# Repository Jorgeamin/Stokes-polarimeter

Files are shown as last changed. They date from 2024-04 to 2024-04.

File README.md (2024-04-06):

# Stokes-polarimeter
Supplement documents for article "Homemade open-source full-Stokes polarimeter based on division of amplitude"

* [python](python): This folder contains python scripts for user interface.\
    main application file **stokes_polarimeter.py**\
     -line 517:  ### Here your put the result of the calibration of the photodiodes ###\
     -line 526:  ### Here your put the result of the calibration to obtain the Stokes parameters ###
  
* [firmware](firmware): This folder contains MPLAB Harmony 3 firmware that should be installed in an ATSAML21E16B\
    file **main.c**\
	-line 97:  /// Here your put the result of the calibration of the photodiodes ///\
	-line 106: /// Here your put the result of the calibration to obtain the Stokes parameters ///
	
* [pcb](pcb): This folder contains the Autodesk Eagle electronic design files.
* [3d](3d): This folder contains the 3D Autodesk Inventor, STEP and STL files.
* [pdf](pdf): This folder contains the electronic diagrams and the 3D assembly in PDF format.

-this repository uses submodules

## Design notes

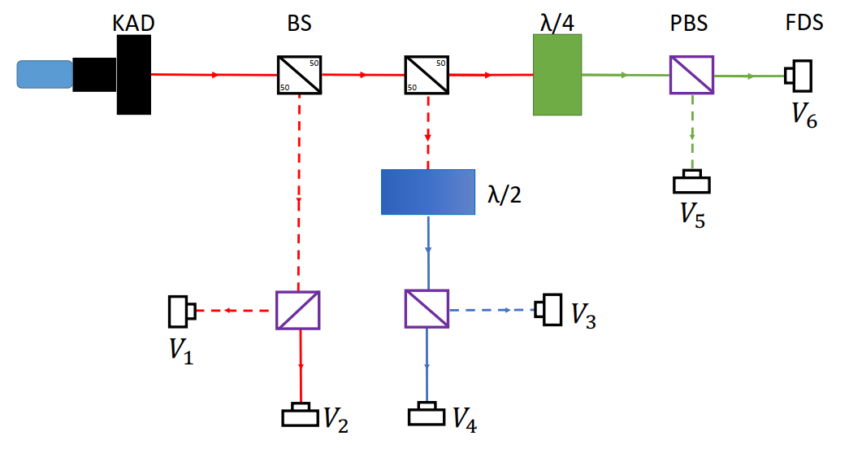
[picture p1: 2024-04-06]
python/figures/Polarization_analyzer_pds.png

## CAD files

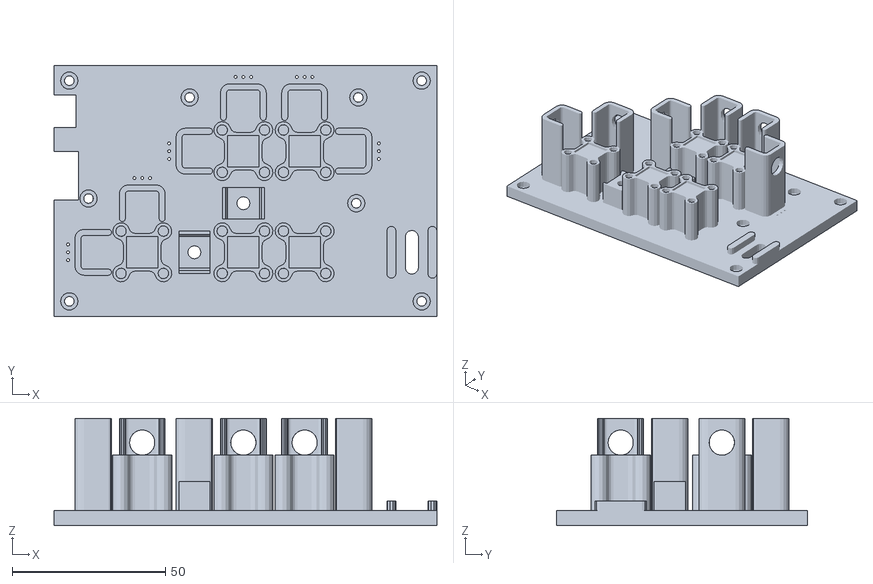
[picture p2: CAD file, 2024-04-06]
3d/3D_printer/base_main.stl
125.0 x 82.0 x 35.0

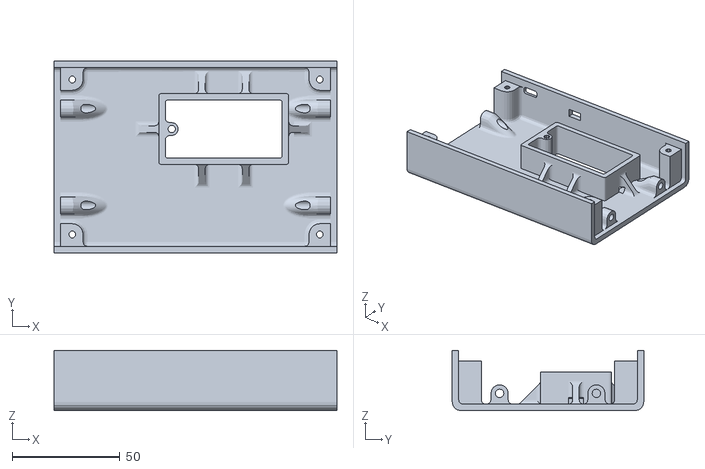
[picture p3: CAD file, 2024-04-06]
3d/3D_printer/case_box.stl
131.5 x 89.0 x 28.0

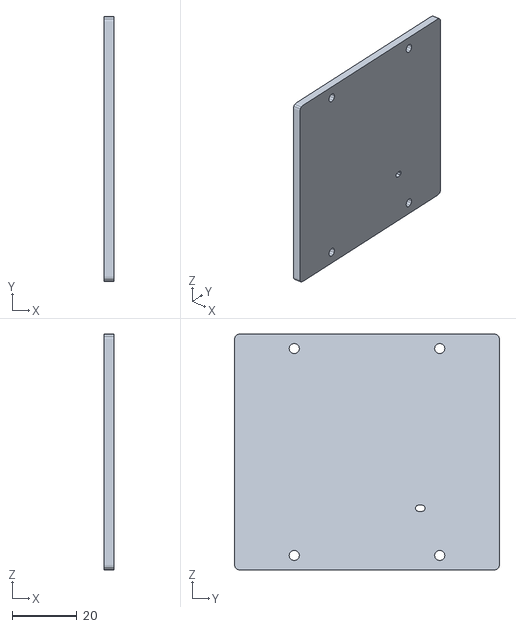
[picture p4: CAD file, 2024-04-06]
3d/3D_printer/case_rear.stl
3.00 x 82.0 x 73.0

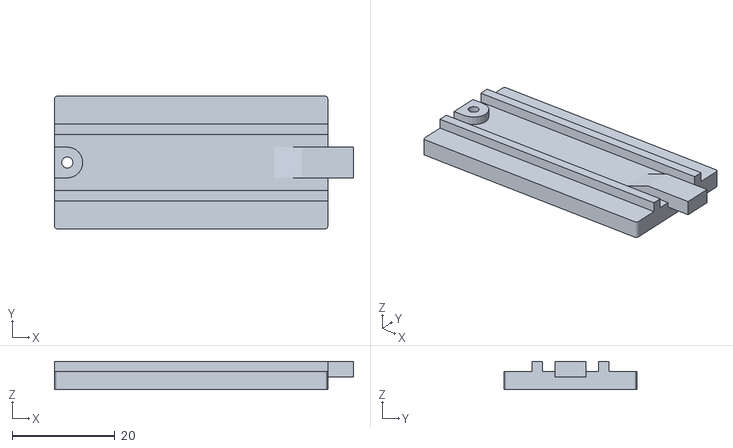
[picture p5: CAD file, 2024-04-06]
3d/3D_printer/case_battery_lid.stl
58.3 x 25.9 x 5.50

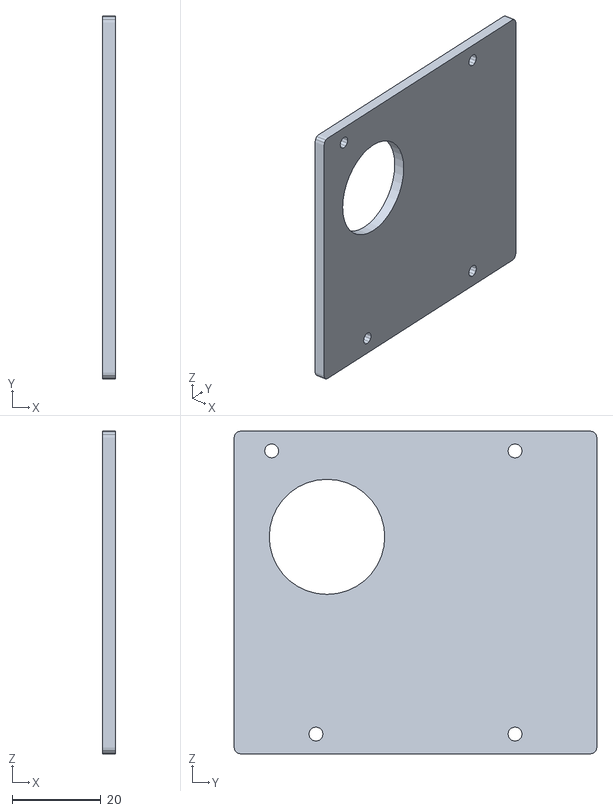
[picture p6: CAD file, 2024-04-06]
3d/3D_printer/case_front.stl
3.00 x 82.0 x 73.0

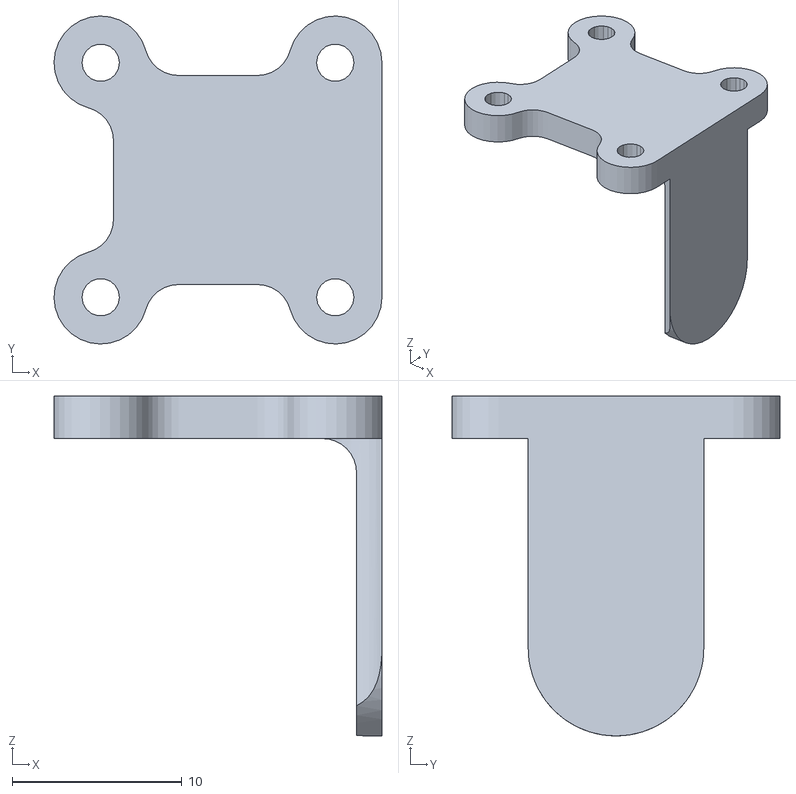
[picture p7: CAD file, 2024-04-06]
3d/3D_printer/lid_cube_wall.stl
19.3 x 19.3 x 20.0

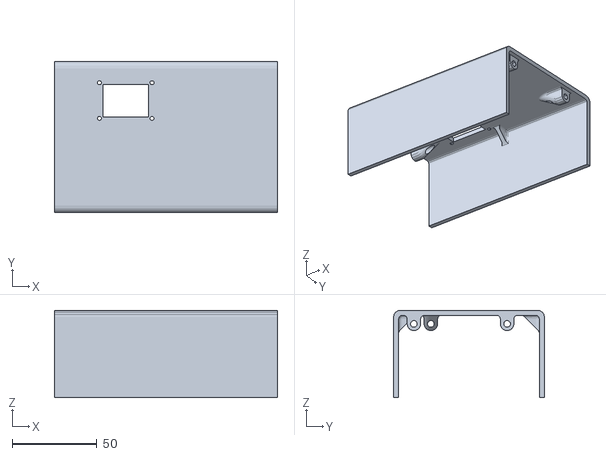
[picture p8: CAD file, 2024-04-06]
3d/3D_printer/case_lid.stl
131.5 x 89.0 x 51.5

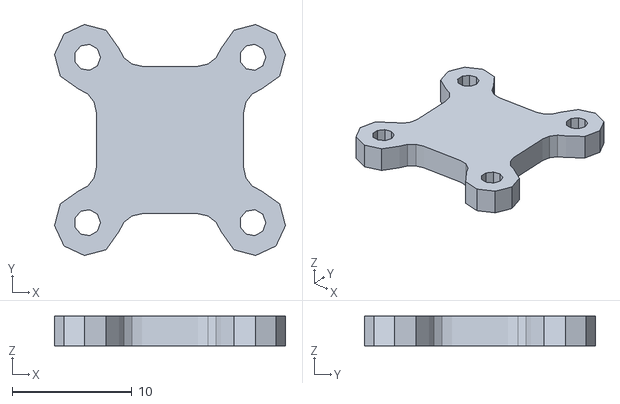
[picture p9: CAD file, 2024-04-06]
3d/3D_printer/lid_cube_x4.stl
19.3 x 19.3 x 2.50

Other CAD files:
3d/Inventor/components/DF13-4S-1.25C.ipt
3d/Inventor/components/Keystone_3348.ipt
3d/Inventor/components/TR Fastenings Ltd-M2X10mm.ipt
3d/Inventor/components/TR Fastenings Ltd-M2X16mm.ipt
3d/Inventor/components/TR Fastenings Ltd-M2_nut.ipt
3d/Inventor/components/TR Fastenings Ltd-M2_termal.ipt
3d/Inventor/components/TR Fastenings Ltd-M3X25mm.ipt
3d/Inventor/components/TR Fastenings Ltd-M3X8mm.ipt
3d/Inventor/components/TR Fastenings Ltd-M3_nut.ipt
3d/Inventor/components/TR Fastenings Ltd-M3_termal.ipt
3d/Inventor/components/TR Fastenings Ltd-M4X10mm.ipt
3d/Inventor/components/TR Fastenings Ltd-M4X18mm.ipt
3d/Inventor/components/acrylic.ipt
3d/Inventor/components/allen_2mm.ipt
3d/Inventor/components/base_cube.ipt
3d/Inventor/components/base_fotodiode.ipt
3d/Inventor/components/base_main.ipt
3d/Inventor/components/base_thor.ipt
3d/Inventor/components/box/battery_lid.ipt
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

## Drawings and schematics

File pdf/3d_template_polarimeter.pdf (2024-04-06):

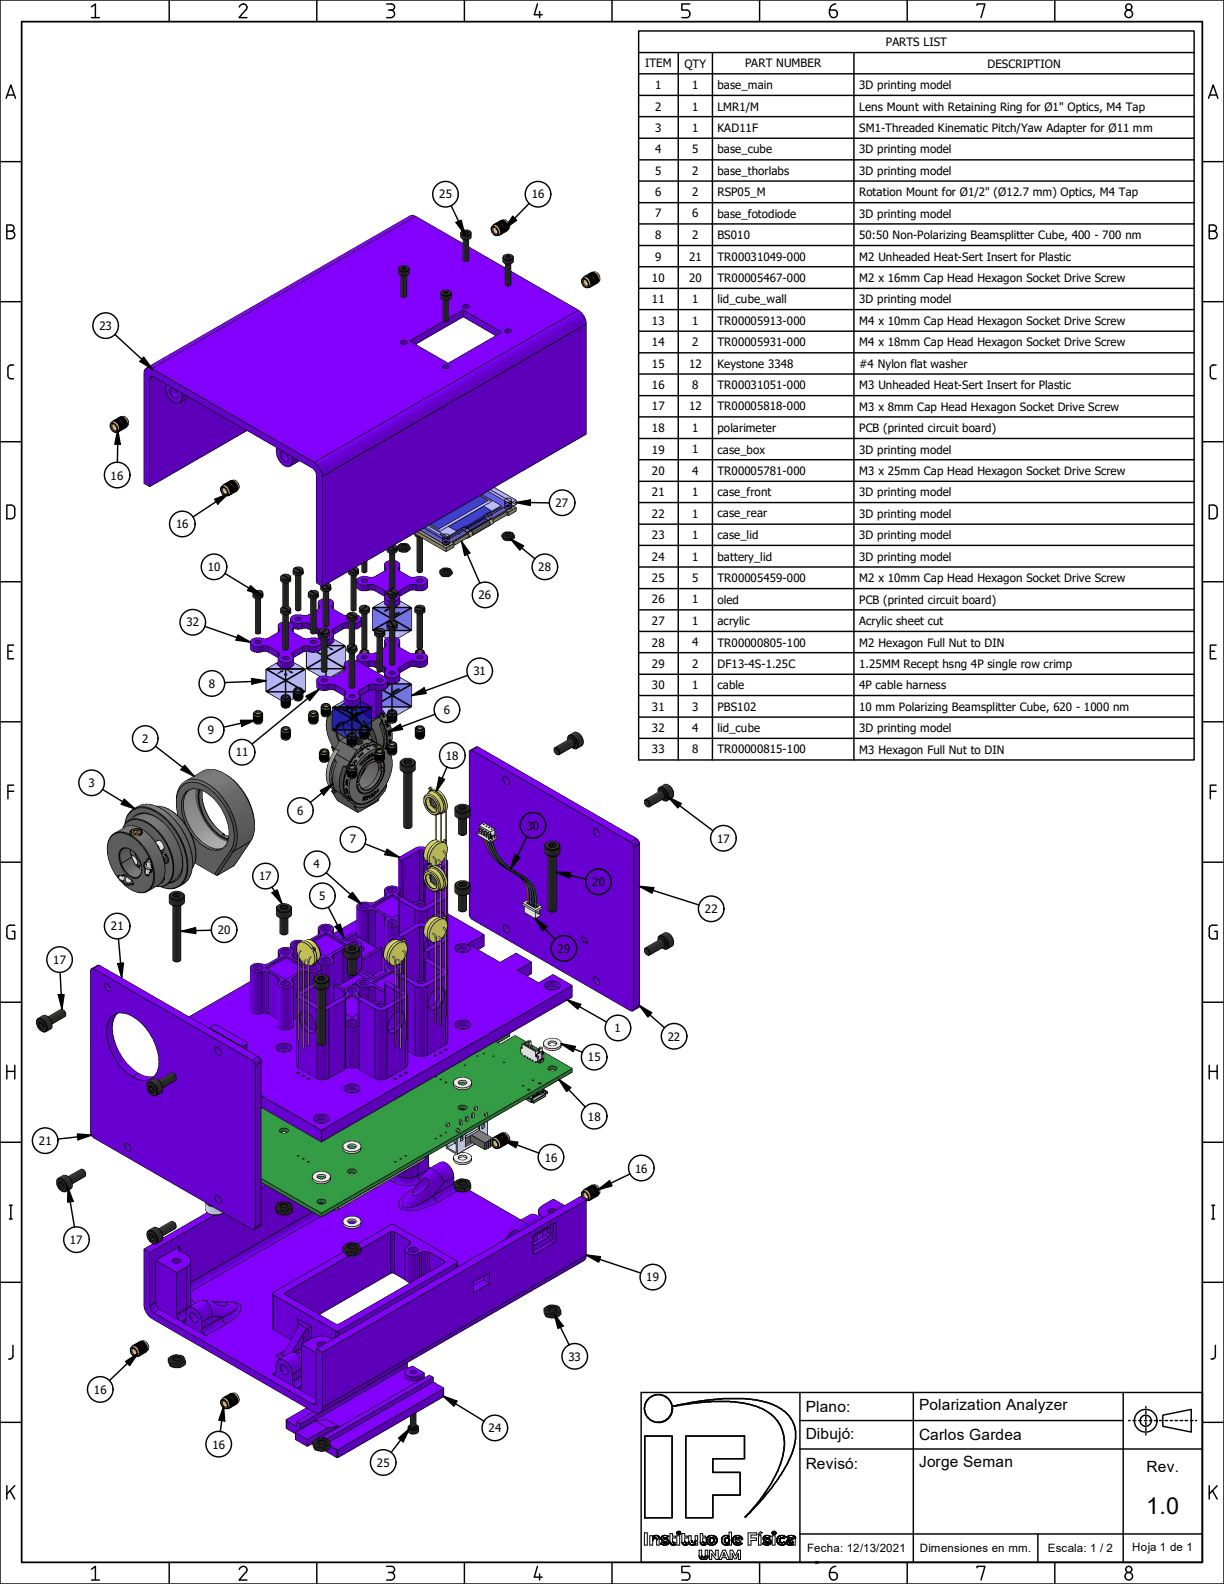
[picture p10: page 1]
PARTS LIST

ITEM | QTY | PART NUMBER | DESCRIPTION

1 | 1 | base_main | 3D printing model

2 | 1 | LMR1/M | Lens Mount with Retaining Ring for Ø1" Optics, M4 Tap

3 | 1 | KAD11F | SM1-Threaded Kinematic Pitch/Yaw Adapter for Ø11 mm

4 | 5 | base_cube | 3D printing model

5 | 2 | base_thorlabs | 3D printing model

6 | 2 | RSP05_M | Rotation Mount for Ø1/2" (Ø12.7 mm) Optics, M4 Tap

7 | 6 | base_fotodiode | 3D printing model

8 | 2 | BS010 | 50:50 Non-Polarizing Beamsplitter Cube, 400 - 700 nm

9 | 21 | TR00031049-000 | M2 Unheaded Heat-Sert Insert for Plastic

10 | 20 | TR00005467-000 | M2 x 16mm Cap Head Hexagon Socket Drive Screw

11 | 1 | lid_cube_wall | 3D printing model

13 | 1 | TR00005913-000 | M4 x 10mm Cap Head Hexagon Socket Drive Screw

14 | 2 | TR00005931-000 | M4 x 18mm Cap Head Hexagon Socket Drive Screw

15 | 12 | Keystone 3348 | #4 Nylon flat washer

16 | 8 | TR00031051-000 | M3 Unheaded Heat-Sert Insert for Plastic

17 | 12 | TR00005818-000 | M3 x 8mm Cap Head Hexagon Socket Drive Screw

18 | 1 | polarimeter | PCB (printed circuit board)

19 | 1 | case_box | 3D printing model

20 | 4 | TR00005781-000 | M3 x 25mm Cap Head Hexagon Socket Drive Screw

21 | 1 | case_front | 3D printing model
22 | 1 | case_rear | 3D printing model

23 | 1 | case_lid | 3D printing model

24 | 1 | battery_lid | 3D printing model

25 | 5 | TR00005459-000 | M2 x 10mm Cap Head Hexagon Socket Drive Screw

26 | 1 | oled | PCB (printed circuit board)

27 | 1 | acrylic | Acrylic sheet cut

28 | 4 | TR00000805-100 | M2 Hexagon Full Nut to DIN

29 | 2 | DF13-4S-1.25C | 1.25MM Recept hsng 4P single row crimp

30 | 1 | cable | 4P cable harness

31 | 3 | PBS102 | 10 mm Polarizing Beamsplitter Cube, 620 - 1000 nm

32 | 4 | lid_cube | 3D printing model

33 | 8 | TR00000815-100 | M3 Hexagon Full Nut to DIN

Plano: | Polarization Analyzer
Dibujó: | Carlos Gardea
Revisó: | Jorge Seman | Rev. 1.0

Fecha: 12/13/2021 | Dimensiones en mm. | Escala: 1 / 2 | Hoja 1 de 1

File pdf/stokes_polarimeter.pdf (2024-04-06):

## ATSAML21

A

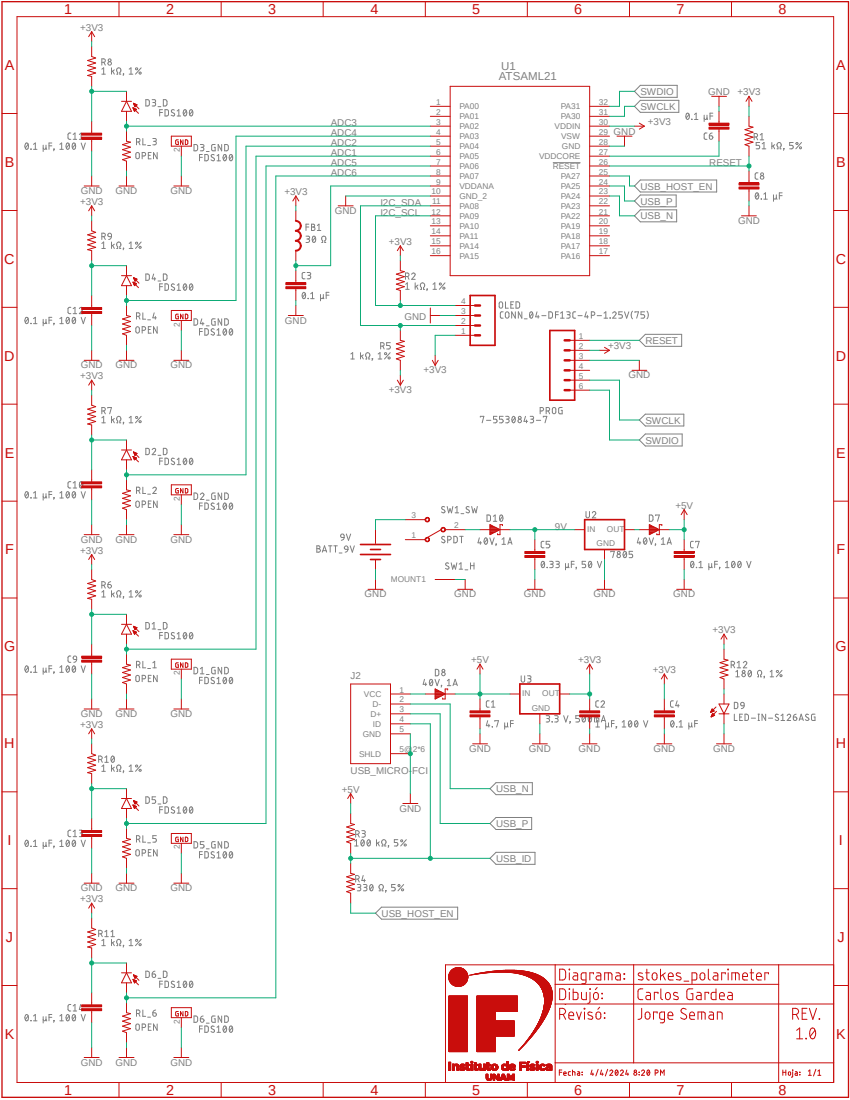
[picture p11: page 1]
USB_MICRO-FCI; GND; GND GND; VCC; 4 GND; 5 SHLD; OUT; VDDANA 9; GND_2 10; 25 RESET; 26 VDDCORE; 27 GND; 28 VSW; 29 VDDIN; 2 MOUNT1; SWDIO; SWCLK; RESET; USB_P; USB_N; USB_ID; USB_HOST_EN; ADC3 ADC4 ADC2 ADC1 ADC5 ADC6; I2C_SDA I2C_SCL

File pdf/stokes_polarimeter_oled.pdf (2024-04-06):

GND | GND

+3V3

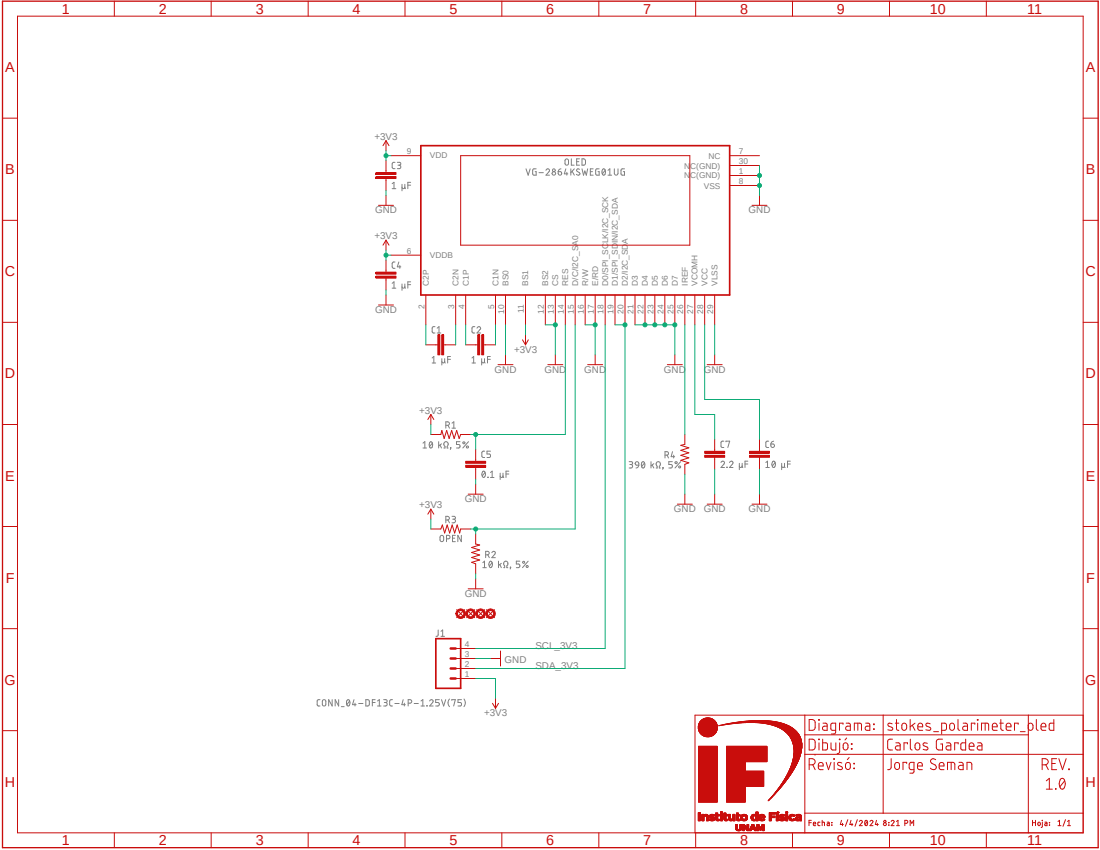
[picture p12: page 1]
GND; GND GND; NC(GND); 30 VLSS 29 VCC 28 VCOMH 27 IREF 26 D⁷ 25 D⁶ 24 D⁵ 23 D⁴ 22 D³ 21 D²/I2C_SDA 20 D¹/SPI_SDIN/I2C_SDA 19 D⁰/SPI_SCLK/I2C_SCK 18 E/RD 17 R/W 16 D/C/I2C_SA⁰ 15 RES 14 CS 13 BS² 12 BS¹ 11 BS⁰ 10 VDD 9; VSS; 7 VDDB 6; C¹N; 4 SCL_3V3; SDA_3V3

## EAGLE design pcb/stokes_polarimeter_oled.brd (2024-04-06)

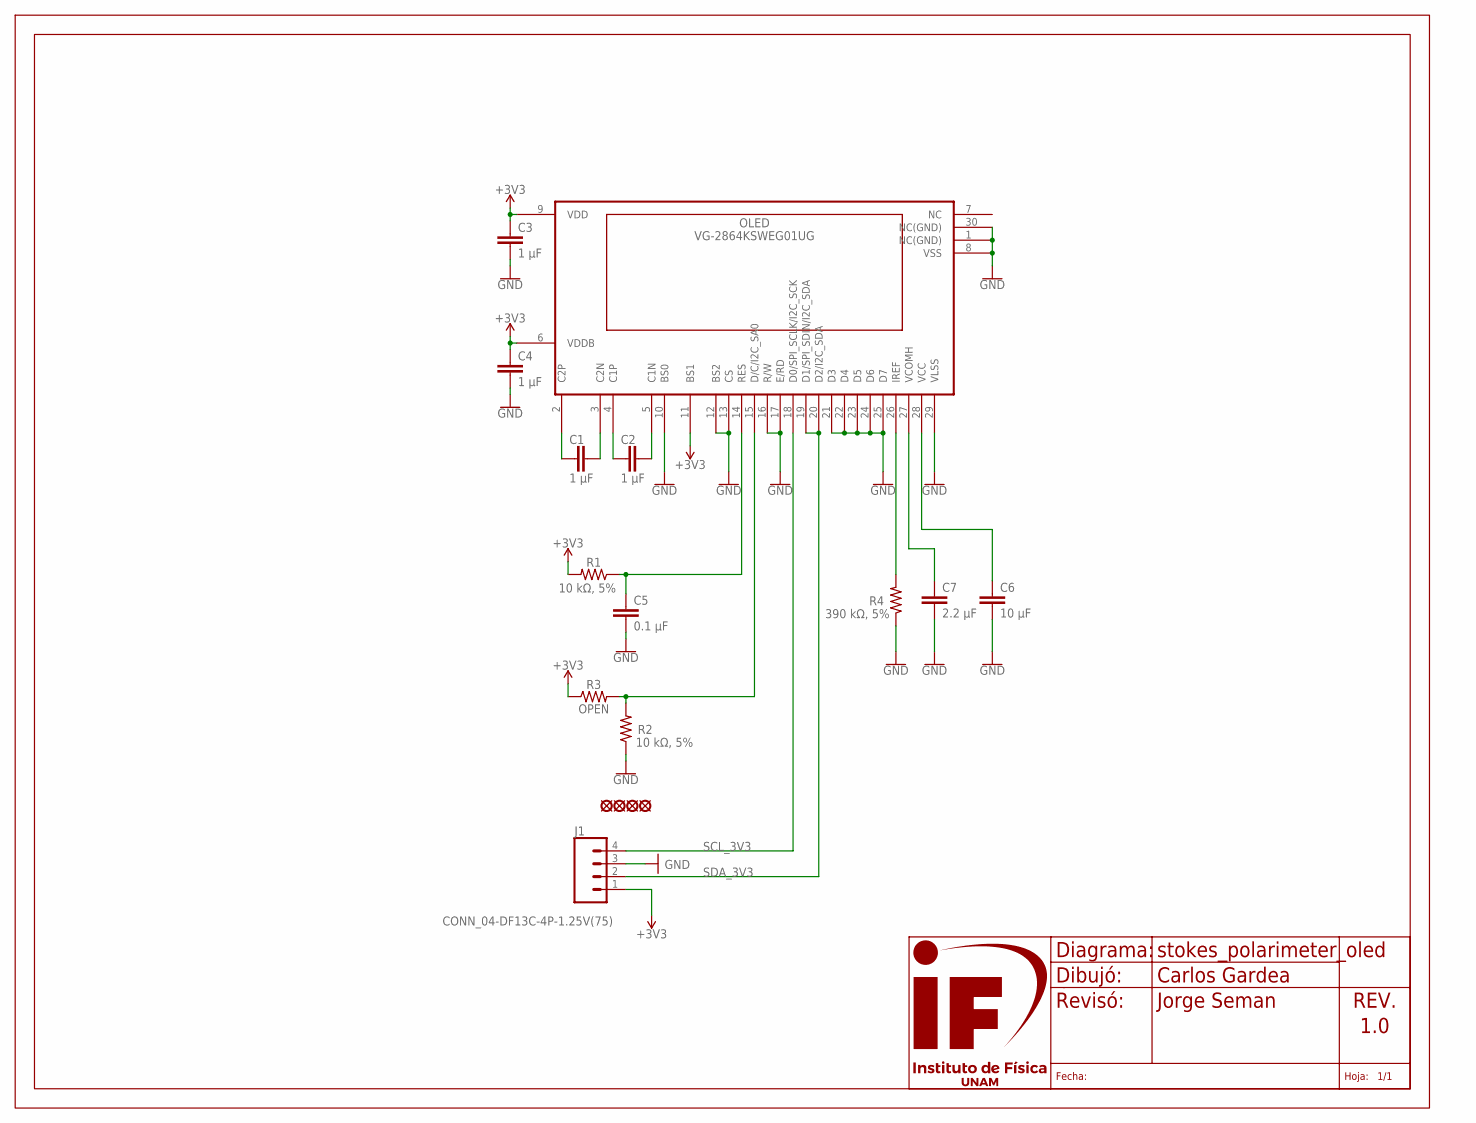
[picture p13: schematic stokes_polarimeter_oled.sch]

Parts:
C1, C2, C3, C4: 1 µF; C1206
C5: 0.1 µF; C1206
C6: 10 µF; C1206
C7: 2.2 µF; C1206
H5, H6, H7, H8: HOLE-M2.5; HOLE_2.5
J1: CONN_04-DF13C-4P-1.25V(75); DF13C4P125V
OLED: VG-2864KSWEG01UG; UG-2864HSWEG01
R1, R2: 10 kΩ, 5%; R1206
R3: OPEN; R1206_OPEN
R4: 390 kΩ, 5%; R1206
U$1: IFUNAM_FRAME_LETTER_HNONE; NONE

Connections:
+3V3: C3.1, C4.1, J1.1, OLED.6 (VDDB), OLED.9 (VDD), OLED.11 (BS1), R1.2, R3.1
GND: C3.2, C4.2, C5.2, C6.2, C7.2, J1.3, OLED.1 (NC(GND)), OLED.8 (VSS), OLED.10 (BS0), OLED.12 (BS2), OLED.13 (CS), OLED.16 (R/W), OLED.17 (E/RD), OLED.21 (D3), OLED.22 (D4), OLED.23 (D5), OLED.24 (D6), OLED.25 (D7), OLED.29 (VLSS), OLED.30 (NC(GND)), R2.1, R4.1
unnamed: C2.1, OLED.4 (C1P)
unnamed: C1.2, OLED.3 (C2N)
unnamed: C1.1, OLED.2 (C2P)
unnamed: C2.2, OLED.5 (C1N)
unnamed: C5.1, OLED.14 (RES), R1.1
unnamed: OLED.15 (D/C/I2C_SA0), R2.2, R3.2
unnamed: OLED.26 (IREF), R4.2
unnamed: C7.1, OLED.27 (VCOMH)
unnamed: C6.1, OLED.28 (VCC)
SCL_3V3: J1.4, OLED.18 (D0/SPI_SCLK/I2C_SCK)
SDA_3V3: J1.2, OLED.19 (D1/SPI_SDIN/I2C_SDA), OLED.20 (D2/I2C_SDA)

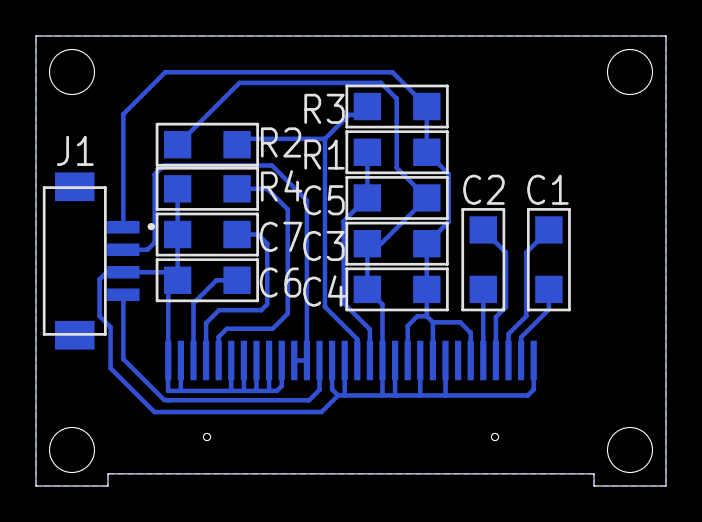
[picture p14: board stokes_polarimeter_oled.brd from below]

Board: 2 copper layers, 35.0 x 25.0 mm, 18 parts (12 on the bottom side), 13 nets.

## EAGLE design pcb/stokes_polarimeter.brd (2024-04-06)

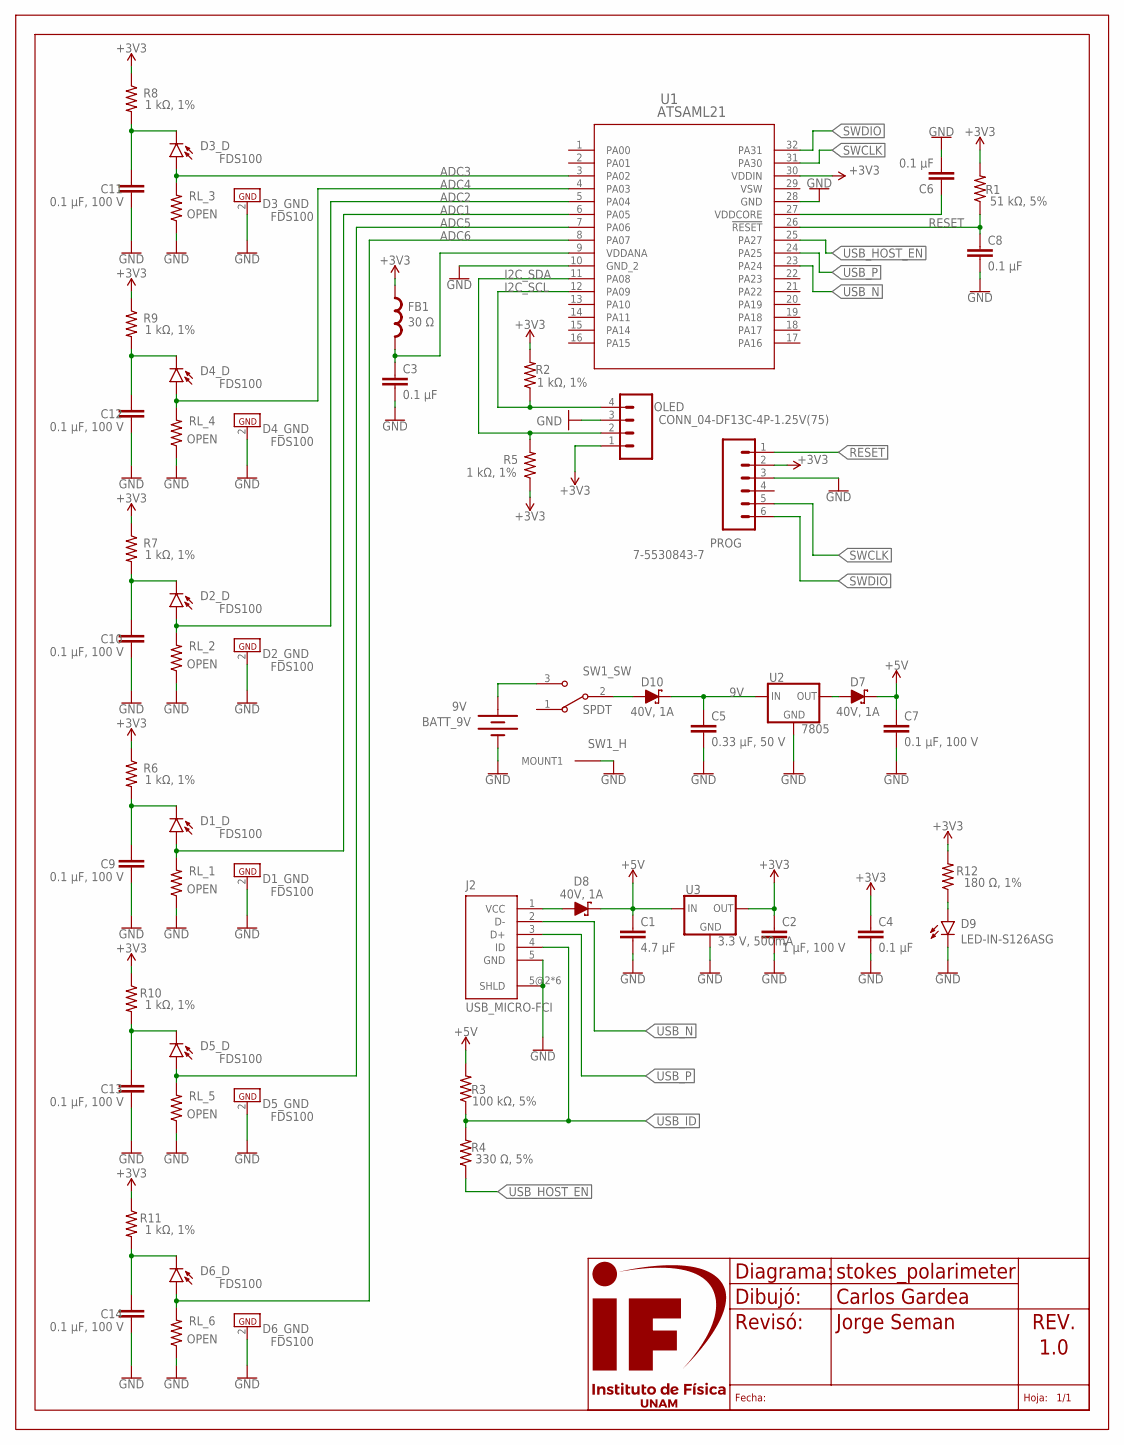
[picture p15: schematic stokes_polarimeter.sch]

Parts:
BATT_9V: 9V; 5331
C1: 4.7 µF; C1206
C2: 1 µF, 100 V; C1206
C3, C4, C6, C8: 0.1 µF; C1206
C5: 0.33 µF, 50 V; C1206
C7, C9, C10, C11, C12, C13, C14: 0.1 µF, 100 V; C1206
D1, D2, D3, D4, D5, D6: FDS100; FDS100_VERT
D7, D8, D10: 40V, 1A; DO-214AC
D9: LED-IN-S126ASG; IN-S126AS
FB1: 30 Ω; L1206
J2: USB_MICRO-FCI; 10103594-0001LF_FCI
OLED: CONN_04-DF13C-4P-1.25V(75); DF13C4P125V
PROG: 7-5530843-7
R1: 51 kΩ, 5%; R1206
R2, R5, R6, R7, R8, R9, R10, R11: 1 kΩ, 1%; R1206
R3: 100 kΩ, 5%; R1206
R4: 330 Ω, 5%; R1206
R12: 180 Ω, 1%; R1206
RL_1, RL_2, RL_3, RL_4, RL_5, RL_6: OPEN; R1206_OPEN
SW1: SPDT; SK12F17G7
U1: ATSAML21; TQFP32
U2: 7805; DPAK
U3: 3.3 V, 500mA; SOT223
U$54: IFUNAM_FRAME_LETTER_VNONE; NONE

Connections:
9V: C5.1, D10.K (C), U2.1 (IN)
+3V3: C2.1, C4.1, FB1.1, OLED.1, PROG.2, R1.2, R2.2, R5.1, R6.1, R7.1, R8.1, R9.1, R10.1, R11.1, R12.2, U1.30 (VDDIN), U3.3 (OUT)
+5V: C1.1, C7.1, D7.K (C), D8.K (C), R3.2, U3.1 (IN)
ADC1: D1.1 (A), RL_1.2, U1.6 (PA05)
ADC2: D2.1 (A), RL_2.2, U1.5 (PA04)
ADC3: D3.1 (A), RL_3.2, U1.3 (PA02)
ADC4: D4.1 (A), RL_4.2, U1.4 (PA03)
ADC5: D5.1 (A), RL_5.2, U1.7 (PA06)
ADC6: D6.1 (A), RL_6.2, U1.8 (PA07)
GND: BATT_9V.-, C1.2, C2.2, C3.2, C4.2, C5.2, C6.2, C7.2, C8.2, C9.2, C10.2, C11.2, C12.2, C13.2, C14.2, D1.2 (P$GND), D2.2 (P$GND), D3.2 (P$GND), D4.2 (P$GND), D5.2 (P$GND), D6.2 (P$GND), D9.K (C), J2.5 (GND), J2.5@2 (SHLD), J2.5@3 (SHLD), J2.5@4 (SHLD), J2.5@5 (SHLD), J2.5@6 (SHLD), J2.5@7 (SHLD), OLED.3, PROG.3, RL_1.1, RL_2.1, RL_3.1, RL_4.1, RL_5.1, RL_6.1, SW1.MH1 (MOUNT1), SW1.MH2 (MOUNT1), SW1.MH3 (MOUNT1), SW1.MH4 (MOUNT1), U1.10 (GND_2), U1.28 (GND), U2.4 (GND), U3.2 (GND), U3.4 (GND)
I2C_SCL: OLED.4, R2.1, U1.12 (PA09)
I2C_SDA: OLED.2, R5.2, U1.11 (PA08)
unnamed: C10.1, D2.3 (C), R7.2
unnamed: D10.A, SW1.2 (COMMON)
unnamed: C9.1, D1.3 (C), R6.2
unnamed: D9.A, R12.1
unnamed: C11.1, D3.3 (C), R8.2
unnamed: BATT_9V.+, SW1.3 (NO)
unnamed: C12.1, D4.3 (C), R9.2
unnamed: C13.1, D5.3 (C), R10.2
unnamed: C14.1, D6.3 (C), R11.2
unnamed: D7.A, U2.3 (OUT)
unnamed: D8.A, J2.1 (VCC)
RESET: C8.1, PROG.1, R1.1, U1.26 (!RESET)
SWCLK: PROG.5, U1.31 (PA30)
SWDIO: PROG.6, U1.32 (PA31)
USB_HOST_EN: R4.1, U1.25 (PA27)
USB_ID: J2.4 (ID), R3.1, R4.2
USB_N: J2.2 (D-), U1.23 (PA24)
USB_P: J2.3 (D+), U1.24 (PA25)
VDDANA: C3.1, FB1.2, U1.9 (VDDANA)
VDDCORE: C6.1, U1.27 (VDDCORE)

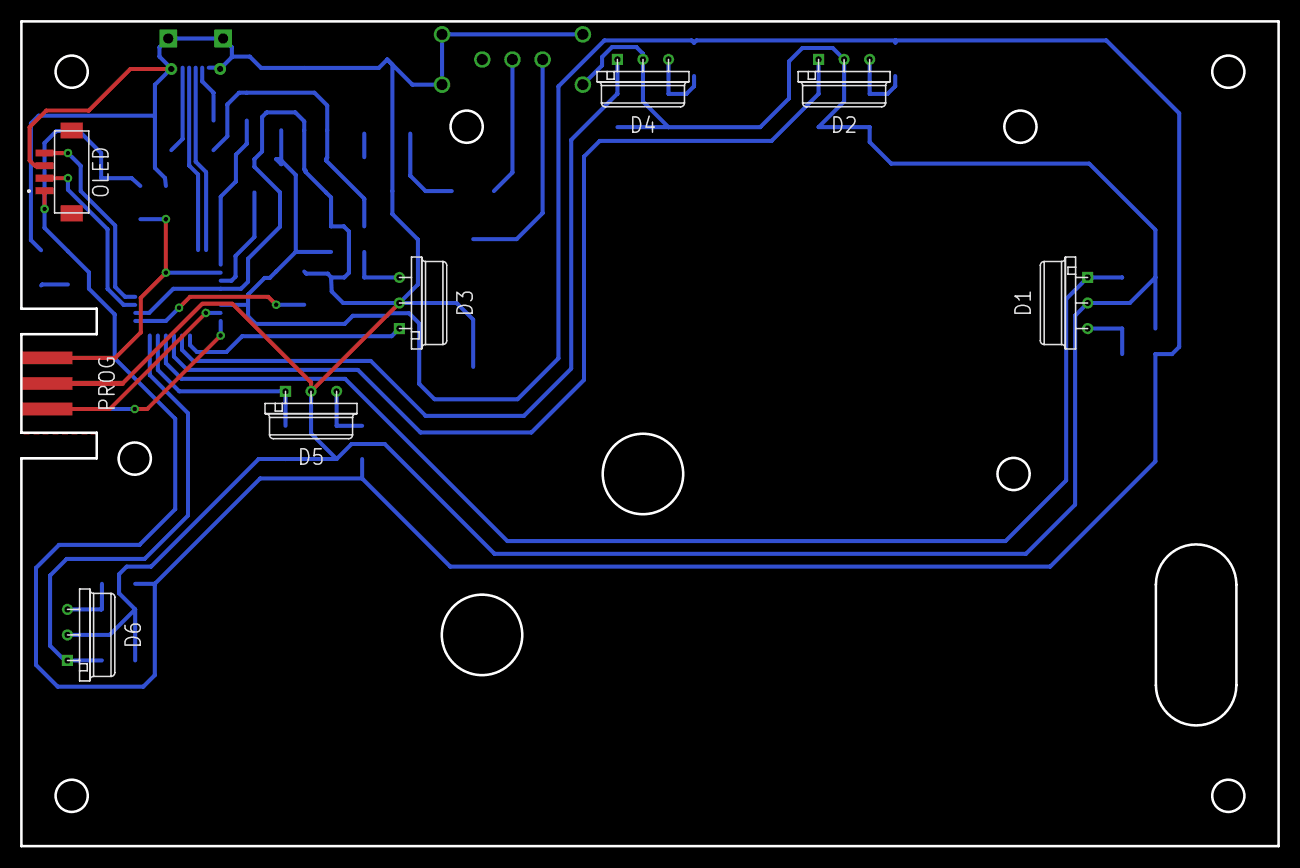
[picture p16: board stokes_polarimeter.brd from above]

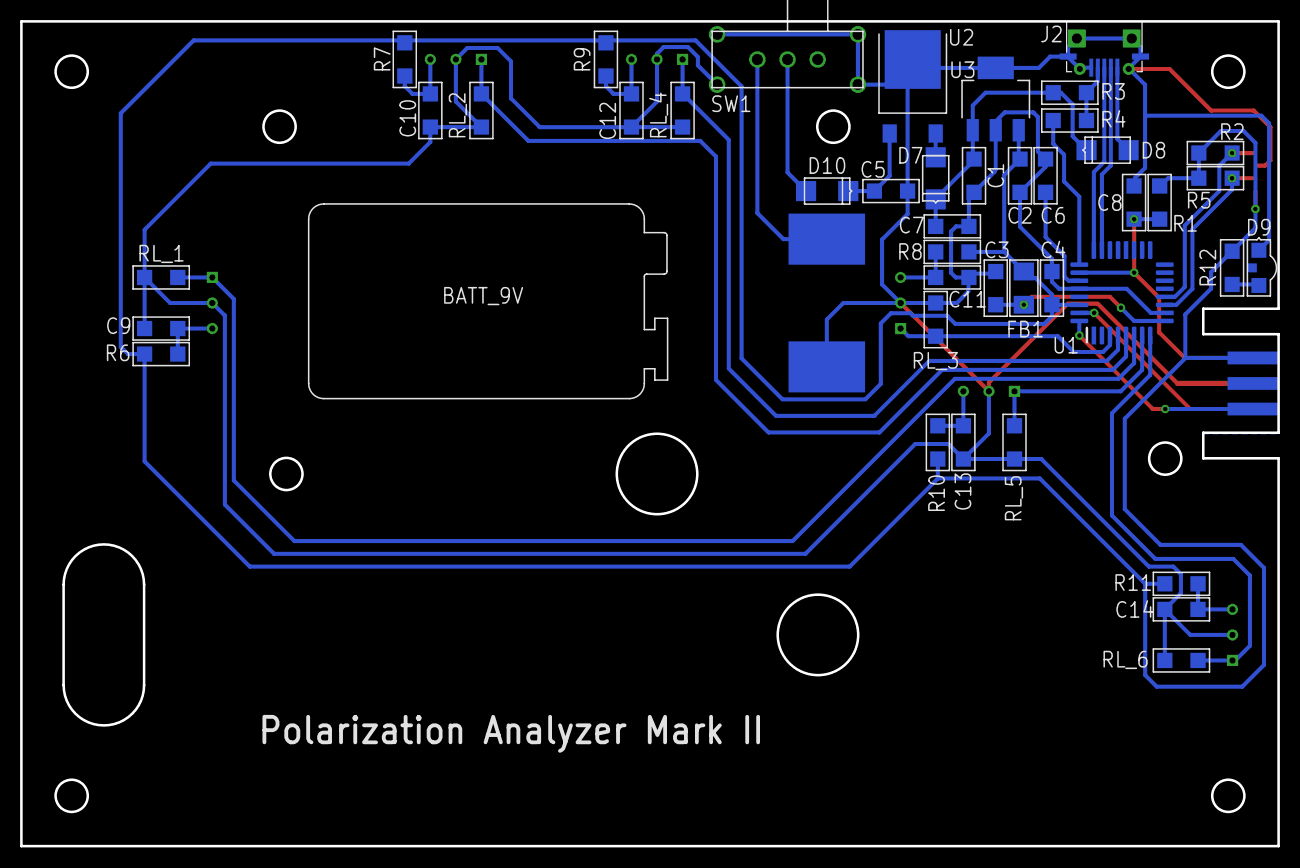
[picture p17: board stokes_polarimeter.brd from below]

Board: 2 copper layers, 125.0 x 82.0 mm, 52 parts (43 on the bottom side), 32 nets.

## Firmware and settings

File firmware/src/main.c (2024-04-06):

#include <stddef.h>                     // Defines NULL
#include <stdbool.h>                    // Defines true
#include <stdlib.h>                     // Defines EXIT_FAILURE
#include "definitions.h"                // SYS function prototypes

#define SSD1306_I2C_ADDRESS 0x3c
#include "oled.h"

#include <math.h>

uint8_t usb_flag = 0, T0_count = 0;
//------------------------------------------------------------------------------USBconnected
void USBconnected( bool flag ){
    if (flag) {
        TC0_TimerStop( );
        usb_flag = 1;
    } 
    else{
        TC0_TimerStart( );
        usb_flag = 0;
    }  
}
//------------------------------------------------------------------------------TC0_Callback_InterruptHandler
void TC0_Callback_InterruptHandler(TC_TIMER_STATUS status, uintptr_t context){
    T0_count ++;   
}
//------------------------------------------------------------------------------main
int main ( void ){    
    char text[50];
    uint8_t i=0;
    
    uint8_t adc_channel = 0;
    uint32_t adc_result[6] = {0,0,0,0,0,0};
    float P1, P2, P3, P4, P5, P6;
    float s0, s1, s2, s3, sp;
    float rho, theta, phi; 
    
    SYS_Initialize ( NULL );
    
    TC0_TimerCallbackRegister(TC0_Callback_InterruptHandler, (uintptr_t)NULL);
    TC0_TimerStop( );
    
    SYS_Tasks ( );
    SSD1306_Begin(SSD1306_SWITCHCAPVCC, SSD1306_I2C_ADDRESS);
    SSD1306_ClearDisplay( );
    
    ADC_Enable();
    SYSTICK_TimerStart();

    sprintf(text, "STOKES POLARIMETER");
    SSD1306_DrawText(7, 0, text,1);

    sprintf(text, "Laboratorio de");
    SSD1306_DrawText(0, 20, text,1);
    sprintf(text, "Materia Ultrafr%ca",132);
    SSD1306_DrawText(0, 32, text,1);
    sprintf(text, "Instituto de F%csica,",132);
    SSD1306_DrawText(0, 44, text,1);
    sprintf(text, "UNAM, M%cxico.",131);
    SSD1306_DrawText(0, 56, text,1);
    SSD1306_Display( );
    
    for(i=0;i<30;i++){ SYSTICK_DelayMs(100); SYS_Tasks ( ); }
    
    while ( true ){
        SYS_Tasks ( );
        
        if (usb_flag == 1){
            usb_flag = 2;
            SSD1306_ClearDisplay( );
            sprintf(text, "USB connected...");
            SSD1306_DrawText(0, 20, text,1);
            SSD1306_Display( );
        }
        
        if (T0_count >= 5){
            T0_count = 0;
            
            for(adc_channel=0; adc_channel<6; adc_channel++) adc_result[adc_channel] = 0;
            
            for(i=0;i<100;i++){
                for(adc_channel=0; adc_channel<6; adc_channel++){
                    switch(adc_channel){
                        case 0: ADC_ChannelSelect(ADC_POSINPUT_AIN5 , ADC_NEGINPUT_GND); break;
                        case 1: ADC_ChannelSelect(ADC_POSINPUT_AIN4 , ADC_NEGINPUT_GND); break;
                        case 2: ADC_ChannelSelect(ADC_POSINPUT_AIN0 , ADC_NEGINPUT_GND); break;
                        case 3: ADC_ChannelSelect(ADC_POSINPUT_AIN1 , ADC_NEGINPUT_GND); break;
                        case 4: ADC_ChannelSelect(ADC_POSINPUT_AIN6 , ADC_NEGINPUT_GND); break;
                        case 5: ADC_ChannelSelect(ADC_POSINPUT_AIN7 , ADC_NEGINPUT_GND); break;
                    }
                    ADC_ConversionStart( );
                    while(!ADC_ConversionStatusGet( ));
                    adc_result[adc_channel] += ADC_ConversionResultGet( );
                }
            }

            /// Here your put the result of the calibration of the photodiodes ///

            P1 = 1.2968033653428095e-06  * (float)adc_result[0]/100.0 +  3.7680259412021290e-06;
            P2 = 1.2092812926212499e-06  * (float)adc_result[1]/100.0 +  7.2934964128664330e-08;
            P3 = 1.3203468312698400e-06  * (float)adc_result[2]/100.0 +  1.6556008864497854e-06;
            P4 = 1.3103954362061186e-06  * (float)adc_result[3]/100.0 +  2.5665541251775657e-06;
            P5 = 1.3046381319438402e-06  * (float)adc_result[4]/100.0 +  3.3777689166981804e-06;
            P6 = 1.2173226504424466e-06  * (float)adc_result[5]/100.0 +  5.1301012725581920e-07;
 
            /// Here your put the result of the calibration to obtain the Stokes parameters ///

            s0 =  2.2677783618600*P1 + 2.0873706253300*P2;
            s1 = -2.2677783618600*P1 + 2.1712784247200*P2;
            s2 = -0.0394642125641*P1 + 0.0377849064663*P2 + 4.825616947450*P3 - 4.930836536400*P4 - 0.927906399583*P5 + 0.949198337031*P6;
            s3 = -0.0637676073187*P1 + 0.0610541278178*P2 + 0.410277000493*P3 - 0.419222836397*P4 - 5.198585720690*P5 + 5.317873573470*P6;

            sp = sqrtf(powf(s1,2.0) + powf(s2,2.0) + powf(s3,2.0));

            rho =   sqrtf(powf(s1/sp,2.0) + powf(s2/sp,2.0) + powf(s3/sp,2.0));
            
            theta = acosf((s3/sp)/(rho))     * 180/M_PI ;
            phi =   atanf((s2/sp) / (s1/sp)) * 180/M_PI ;
            

            SSD1306_ClearDisplay( );
            
            sprintf(text, "s0=%.04gmW",s0*1e3);         SSD1306_DrawText(0, 0, text,1);
            sprintf(text, "s1=%.04gmW",s1*1e3);         SSD1306_DrawText(0, 10, text,1);
            sprintf(text, "s2=%.04gmW",s2*1e3);         SSD1306_DrawText(0, 20, text,1);
            sprintf(text, "s3=%.04gmW",s3*1e3);         SSD1306_DrawText(0, 30, text,1);

            sprintf(text, "%c=%0.4g",127, rho);         SSD1306_DrawText(70, 30, text,1);//rho
            sprintf(text, "%c=%0.4g%c",126,theta,129);  SSD1306_DrawText(70, 40, text,1);//theta
            sprintf(text, "%c=%0.4g%c",128,phi,129);    SSD1306_DrawText(70, 50, text,1);//phi
            SSD1306_Display( );
        } 
    }
    return ( EXIT_FAILURE );
}

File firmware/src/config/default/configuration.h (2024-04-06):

/*******************************************************************************
  System Configuration Header

  File Name:
    configuration.h

  Summary:
    Build-time configuration header for the system defined by this project.

  Description:
    An MPLAB Project may have multiple configurations.  This file defines the
    build-time options for a single configuration.

  Remarks:
    This configuration header must not define any prototypes or data
    definitions (or include any files that do).  It only provides macro
    definitions for build-time configuration options

*******************************************************************************/

// DOM-IGNORE-BEGIN
/*******************************************************************************
* Copyright (C) 2018 Microchip Technology Inc. and its subsidiaries.
*
* Subject to your compliance with these terms, you may use Microchip software
* and any derivatives exclusively with Microchip products. It is your
* responsibility to comply with third party license terms applicable to your
* use of third party software (including open source software) that may
* accompany Microchip software.
*
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
* IN NO EVENT WILL MICROCHIP BE LIABLE FOR ANY INDIRECT, SPECIAL, PUNITIVE,
* INCIDENTAL OR CONSEQUENTIAL LOSS, DAMAGE, COST OR EXPENSE OF ANY KIND
* WHATSOEVER RELATED TO THE SOFTWARE, HOWEVER CAUSED, EVEN IF MICROCHIP HAS
* BEEN ADVISED OF THE POSSIBILITY OR THE DAMAGES ARE FORESEEABLE. TO THE
* FULLEST EXTENT ALLOWED BY LAW, MICROCHIP'S TOTAL LIABILITY ON ALL CLAIMS IN
* ANY WAY RELATED TO THIS SOFTWARE WILL NOT EXCEED THE AMOUNT OF FEES, IF ANY,
* THAT YOU HAVE PAID DIRECTLY TO MICROCHIP FOR THIS SOFTWARE.
*******************************************************************************/
// DOM-IGNORE-END

#ifndef CONFIGURATION_H
#define CONFIGURATION_H

// *****************************************************************************
// *****************************************************************************
// Section: Included Files
// *****************************************************************************
// *****************************************************************************
/*  This section Includes other configuration headers necessary to completely
    define this configuration.
*/

#include "user.h"
#include "device.h"

// DOM-IGNORE-BEGIN
#ifdef __cplusplus  // Provide C++ Compatibility

extern "C" {

#endif
// DOM-IGNORE-END

// *****************************************************************************
// *****************************************************************************
// Section: System Configuration
// *****************************************************************************
// *****************************************************************************



// *****************************************************************************
// *****************************************************************************
// Section: System Service Configuration
// *****************************************************************************
// *****************************************************************************


// *****************************************************************************
// *****************************************************************************
// Section: Driver Configuration
// *****************************************************************************
// *****************************************************************************
/* I2C Driver Instance 0 Configuration Options */
#define DRV_I2C_INDEX_0                       0
#define DRV_I2C_CLIENTS_NUMBER_IDX0           1
#define DRV_I2C_QUEUE_SIZE_IDX0               2
#define DRV_I2C_CLOCK_SPEED_IDX0              100

/* I2C Driver Common Configuration Options */
#define DRV_I2C_INSTANCES_NUMBER              1




// *****************************************************************************
// *****************************************************************************
// Section: Middleware & Other Library Configuration
// *****************************************************************************
// *****************************************************************************
/* Number of Endpoints used */
#define DRV_USBFSV1_ENDPOINTS_NUMBER                        3

/* The USB Device Layer will not initialize the USB Driver */
#define USB_DEVICE_DRIVER_INITIALIZE_EXPLICIT

/* Maximum device layer instances */
#define USB_DEVICE_INSTANCES_NUMBER                         1

/* EP0 size in bytes */
#define USB_DEVICE_EP0_BUFFER_SIZE                          64

/* Enable SOF Events */
#define USB_DEVICE_SOF_EVENT_ENABLE


/* Maximum instances of CDC function driver */
#define USB_DEVICE_CDC_INSTANCES_NUMBER                     1


/* CDC Transfer Queue Size for both read and
   write. Applicable to all instances of the
   function driver */
#define USB_DEVICE_CDC_QUEUE_DEPTH_COMBINED                 3
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

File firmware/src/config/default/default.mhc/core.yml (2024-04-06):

format_version: v1.0
type: UniqueComponent
attributes: {id: core}
children:
- type: Symbols
  children:
  - type: Boolean
    attributes: {id: ADC_CLOCK_ENABLE}
    children:
    - type: Values
      children:
      - type: Dynamic
        attributes: {id: adc, value: 'true'}
  - type: Integer
    attributes: {id: ADC_CLOCK_FREQUENCY}
    children:
    - type: Values
      children:
      - type: Dynamic
        attributes: {id: core, value: '48000000'}
  - type: Integer
    attributes: {id: BACKUP_CLOCK_FREQUENCY}
    children:
    - type: Values
      children:
      - type: Dynamic
        attributes: {id: core, value: '6000000'}
  - type: KeyValueSet
    attributes: {id: COMPILER_CHOICE}
    children:
    - type: Values
      children:
      - type: Dynamic
        attributes: {id: core, value: '0'}
  - type: Boolean
    attributes: {id: CONFIG_CLOCK_DFLL_BYPASS_COARSE}
    children:
    - type: Values
      children:
      - type: User
        attributes: {value: 'false'}
  - type: Boolean
    attributes: {id: CONFIG_CLOCK_DFLL_ENABLE}
    children:
    - type: Values
      children:
      - type: Dynamic
        attributes: {id: core, value: 'true'}
      - type: User
        attributes: {value: 'true'}
  - type: Boolean
    attributes: {id: CONFIG_CLOCK_DPLL_ENABLE}
    children:
    - type: Values
      children:
      - type: User
        attributes: {value: 'false'}
  - type: KeyValueSet
    attributes: {id: CONFIG_CLOCK_DPLL_REF_CLOCK}
    children:
    - type: Values
      children:
      - type: User
        attributes: {value: '2'}
  - type: Boolean
    attributes: {id: CONFIG_CLOCK_OSC16M_ENABLE}
    children:
    - type: Values
      children:
      - type: User
        attributes: {value: 'true'}
  - type: KeyValueSet
    attributes: {id: CONFIG_CLOCK_OSC16M_FREQSEL}
    children:
    - type: Values
      children:
      - type: User
        attributes: {value: '1'}
  - type: Integer
    attributes: {id: CPU_CLOCK_FREQUENCY}
    children:
    - type: Values
      children:
      - type: Dynamic
        attributes: {id: core, value: '48000000'}
  - type: Menu
    attributes: {id: CoreIARMenu}
    children:
    - type: Attributes
      children:
      - type: Boolean
        attributes: {id: visible}
        children:
        - {type: Value, value: 'false'}
  - type: Menu
    attributes: {id: CoreKEILMenu}
    children:
    - type: Attributes
      children:
      - type: Boolean
        attributes: {id: visible}
        children:
        - {type: Value, value: 'false'}
  - type: KeyValueSet
    attributes: {id: DEVICE_SECURITY_CMD}
    children:
    - type: Values
      children:
      - type: Dynamic
        attributes: {id: core, value: '0'}
  - type: Integer
    attributes: {id: DFLL_CLOCK_FREQ}
    children:
    - type: Values
      children:
      - type: Dynamic
        attributes: {id: core, value: '48000000'}
  - type: Integer
    attributes: {id: GCLK_0_FREQ}
    children:
    - type: Values
      children:
      - type: Dynamic
        attributes: {id: core, value: '48000000'}
  - type: KeyValueSet
    attributes: {id: GCLK_0_SRC}
    children:
    - type: Values
      children:
      - type: Dynamic
        attributes: {id: core, value: '3'}
      - type: User
        attributes: {value: '3'}
  - type: Integer
    attributes: {id: GCLK_1_DIV}
    children:
    - type: Values
      children:
      - type: User
        attributes: {value: '8'}
  - type: Integer
    attributes: {id: GCLK_1_DIVIDER_VALUE}
    children:
    - type: Values
      children:
      - type: Dynamic
        attributes: {id: core, value: '8'}
  - type: Integer
    attributes: {id: GCLK_1_FREQ}
    children:
    - type: Values
      children:
      - type: Dynamic
        attributes: {id: core, value: '1000000'}
  - type: KeyValueSet
    attributes: {id: GCLK_1_SRC}
    children:
    - type: Values
      children:
      - type: User
        attributes: {value: '1'}
  - type: Integer
    attributes: {id: GCLK_2_FREQ}
    children:
    - type: Values
      children:
      - type: Dynamic
        attributes: {id: core, value: '0'}
  - type: Integer
    attributes: {id: GCLK_3_FREQ}
    children:
    - type: Values
      children:
      - type: Dynamic
        attributes: {id: core, value: '0'}
  - type: Integer
    attributes: {id: GCLK_4_FREQ}
    children:
    - type: Values
      children:
      - type: Dynamic
        attributes: {id: core, value: '0'}
  - type: Integer
    attributes: {id: GCLK_5_FREQ}
    children:
    - type: Values
      children:
      - type: Dynamic
        attributes: {id: core, value: '0'}
  - type: Integer
    attributes: {id: GCLK_6_FREQ}
    children:
    - type: Values
      children:
      - type: Dynamic
        attributes: {id: core, value: '0'}
  - type: Integer
    attributes: {id: GCLK_7_FREQ}
    children:
    - type: Values
      children:
      - type: Dynamic
        attributes: {id: core, value: '0'}
  - type: Integer
    attributes: {id: GCLK_8_FREQ}
    children:
    - type: Values
      children:
      - type: Dynamic
        attributes: {id: core, value: '0'}
  - type: ListEntry
    attributes: {id: GCLK_CODE}
    children:
    - type: Attributes
      children:
      - type: StringArray
        attributes: {id: values}
        children:
        - type: Values
          children:
          - {type: Value, value: '    DFLL_Initialize();'}
          - {type: Value, value: '    GCLK1_Initialize();'}
          - {type: Value, value: '    GCLK0_Initialize();'}
  - type: Boolean
    attributes: {id: GCLK_CYCLE_FORMED}
    children:
    - type: Values
      children:
      - type: Dynamic
        attributes: {id: core, value: 'false'}
  - type: Boolean
    attributes: {id: GCLK_ID_0_CHEN}
    children:
    - type: Values
      children:
      - type: User
        attributes: {value: 'false'}
  - type: Integer
    attributes: {id: GCLK_ID_0_FREQ}
    children:
    - type: Values
      children:
      - type: Dynamic
        attributes: {id: core, value: '0'}
  - type: KeyValueSet
    attributes: {id: GCLK_ID_0_GENSEL}
    children:
    - type: Values
      children:
      - type: User
        attributes: {value: '1'}
  - type: Boolean
    attributes: {id: GCLK_ID_18_CHEN}
    children:
    - type: Values
      children:
      - type: Dynamic
        attributes: {id: core, value: 'true'}
  - type: Integer
    attributes: {id: GCLK_ID_18_FREQ}
    children:
    - type: Values
      children:
      - type: Dynamic
        attributes: {id: core, value: '48000000'}
  - type: Boolean
    attributes: {id: GCLK_ID_27_CHEN}
    children:
    - type: Values
      children:
      - type: Dynamic
        attributes: {id: core, value: 'true'}
  - type: Integer
    attributes: {id: GCLK_ID_27_FREQ}
    children:
    - type: Values
      children:
      - type: Dynamic
        attributes: {id: core, value: '48000000'}
  - type: Boolean
    attributes: {id: GCLK_ID_30_CHEN}
    children:
    - type: Values
      children:
      - type: Dynamic
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
